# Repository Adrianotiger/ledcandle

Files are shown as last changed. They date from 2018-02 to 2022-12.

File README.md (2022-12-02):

# ledcandle
Led candle with push button and timer for auto power off

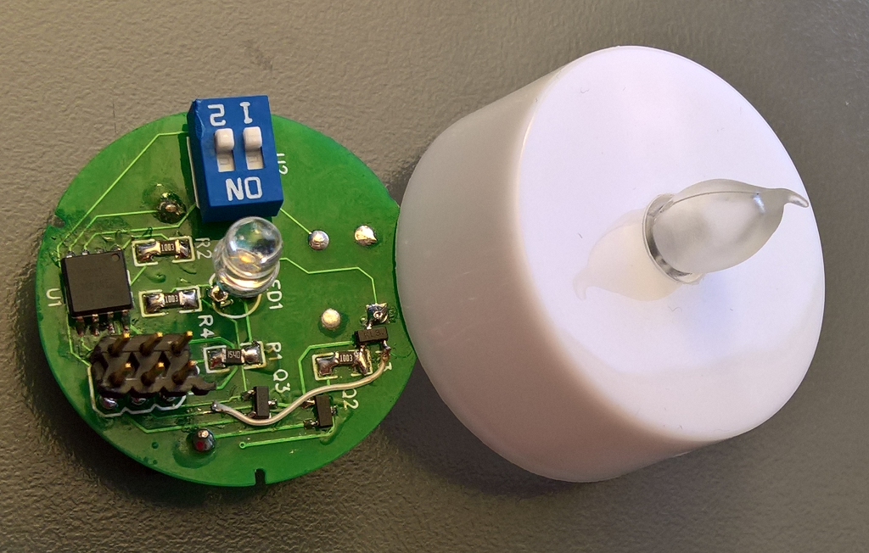
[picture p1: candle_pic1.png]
Candle PCB and case


A project for my [childs room-sky](https://www.youtube.com/watch?v=BvMHdN5_T0Q), it is a candle:
- with auto power off after 10 minutes
- nice and harmonic flicker effects (not aggressive)
- durable, will not be empty after 1 night. Should works for 1 year.
- small, so you can place it in a standard tea-light candle.

It works with an ATTiny45V (Arduino project)

Schematics and PCB are open source and hosted on Easy Eda (see PCB folder): 

https://easyeda.com/tiger54/led_candle-13fe66ec4c4447c1abb9b866b1f16509

3D-print design are hosted on Tinkercad (see 3d-print folder): 

https://www.tinkercad.com/things/0Jzv9iGX0FP
https://www.tinkercad.com/things/gcvcmAciCn8

Copy of the schematics and the Arduino code is hosted on GitHub.

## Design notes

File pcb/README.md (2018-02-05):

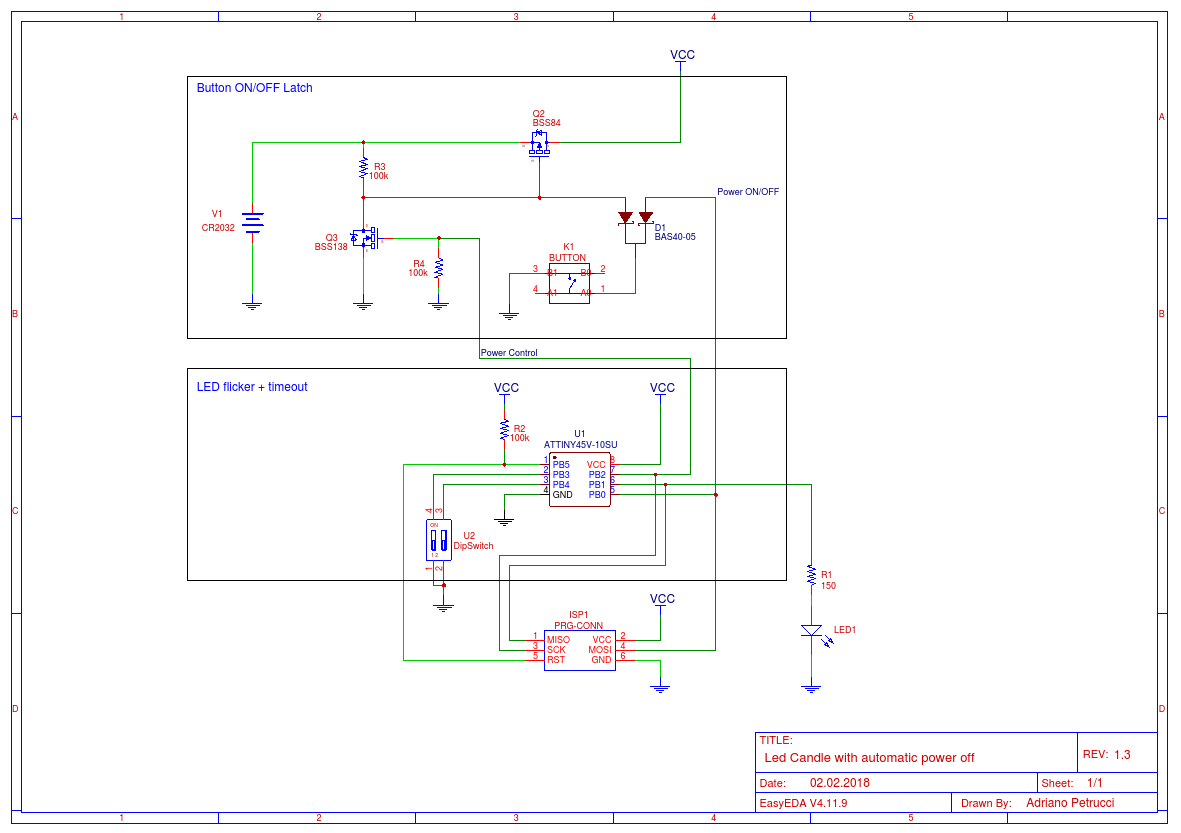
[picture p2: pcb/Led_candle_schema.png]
Led Candle Schema, version 1.3


# Schematics

## How it works
The print is divided in 2 parts. A power latch and the timer control.
Once you press the push bush button, the µC will be powered and will auto power itself until the timeout is over or if the push button is pressed again.
There is a dipswitch that can be used to set some variables inside the code or to program the attiny.

## components / BOM

| Qty | Component | Price ($) | Description |
|-----|---|---|---|
|  1  | V1, Battery holder | 0.06$ | A simple 2032 battery with 230mAh, will power the module for 25-40 hours |
|  1  | Q2, BSS84 | 0.02$ | P-channel MOSFET. Once the switch is pressed, the FET will power on the entire module (VCC = battery voltage) |
|  1  | Q3, BSS138 | 0.02$ | N-channel MOSFET. The µC will activate it (high on gate). Once the µC will set the gate to low, the P-MOSFET will close (VCC = 0V) |
|  1  | K1, Push button | 0.02$ | To power on (and power off) the module. In my project I use a bridge near the LED |
|  1  | LED | 0.01$ | A bright yellow/orange/ambra LED. Something like 8000 mcd at 20mA. Search a LED that works with 1-2V, not 4-5V! |
|  1  | R2,R3,R4 100kΩ | 0.01$ | 2 pullups and 1 pulldown resistors, 10k would also works, but R3 should be as high as possible |
|  1  | R1 150Ω | 0.01$ | LED resistor, choose the resistor for your LED. You should not power the LED with more than 20mA - 5mA in my project |
|  1  | ISP1 Conn. | 0.01$ | A connector (if you want) to program the ATTiny45V, holes are enough small to put the programming connector directly in the PCB |
|  1  | U2 DipSwitch | 0.15$ | Not necessary, you can bridge the pins directly, as this is an expensive component |
|  1  | D1 BAS40-05 | 0.02$ | Dual schottky diode. You need this if you want detect a second press over the µC.* |
|  1  | U1 ATTiny45V | 1.40$ | AT Tiny45 V, is like the AT Tiny45 but you can power it from 1.8V to 5.5V (the normal one only from 2.7 to 5.5V)** |
|  ∞  | 2032 Battery | 0.50$ | A simple 2032 battery, you can get them from 0.10$ up to 1$. Don't know if there is a big difference) |
|  1  | PCB print | 0.40$ | If you buy 5, you have to pay 2$ on easyeda.com |

## Troubles
***Schottky (D1):***

The main problem there is the reverse current. The module will consume even if it should be powered off. *BAS40-05* has only 10nA reverse current, in this way you can detect the switch wihtout loose too much current - you will loose 1% of your battery capacity each year. 
Another way is to remove the connection between µC and switch (cut the track on the PCB between the 2 pads). You will not be able to power off the led anymore but the module will power on also after 10 years.

***ATTiny45V (U1):***

Pratically impossible to find on cheaps shops, this ATTiny is made to works on low voltages. The normal ATTiny works with at least 2.7V but the 3V battery will go down up to 2.0V when discharging. So the only way is to use this V-type ATTiny. The rest is perfect:
4kB program memory, 256 bytes of RAM and even 256 bytes of ROM with a clock that works up to 10MHz (we use only 2kB and 50 bytes of RAM and need a clock of 1MHz, this will reduce the consumption a little bit).

***MOSFETS:***

BSS84 and BSS138, maybe not the best ones but the cheapest on the market. Perfect for this work.

***Battery Holder***

The one used on this project is really big! There are smaller holders, SMD holders for example. If you want a flat module, you have to choose another type.

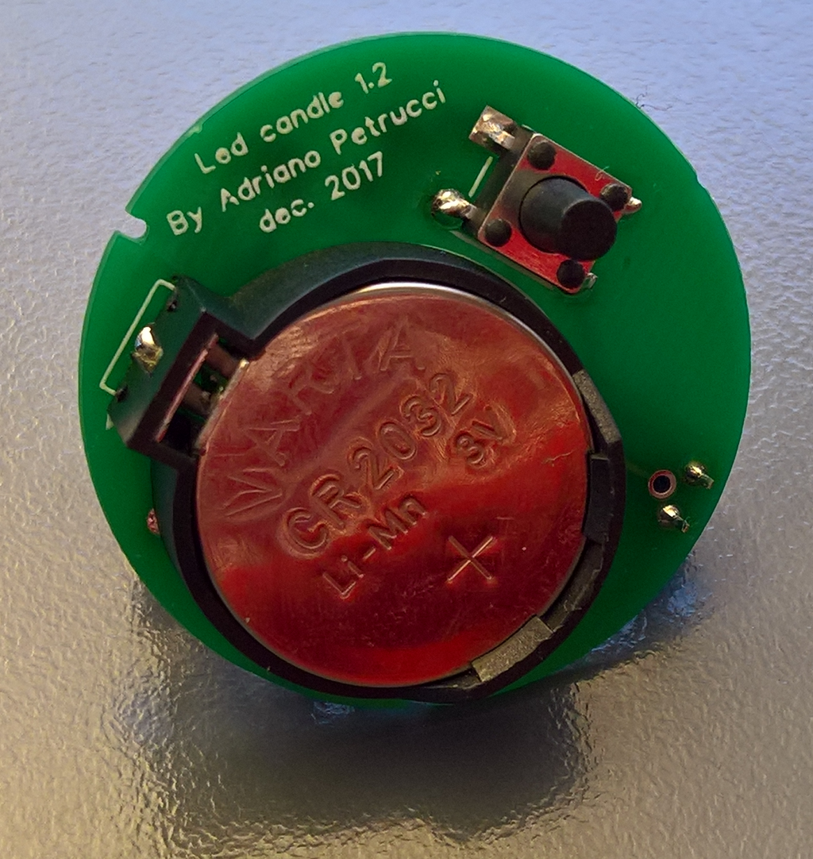
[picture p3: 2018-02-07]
candle_pic2.png

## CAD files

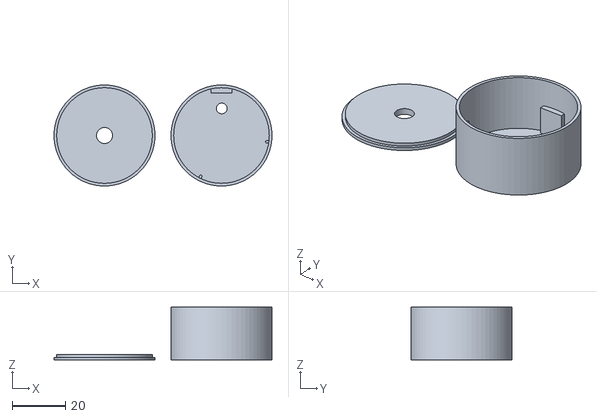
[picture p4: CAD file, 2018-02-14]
3d-print/Led Candle.stl
82.0 x 38.0 x 19.9

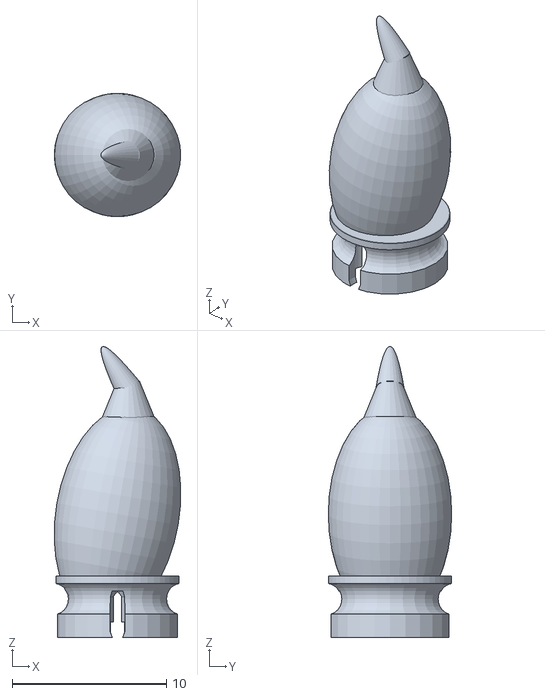
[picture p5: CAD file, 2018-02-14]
3d-print/Led Flame.stl
8.20 x 8.00 x 18.9

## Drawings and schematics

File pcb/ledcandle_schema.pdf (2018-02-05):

### VCC

## Button ON/OFF Latch

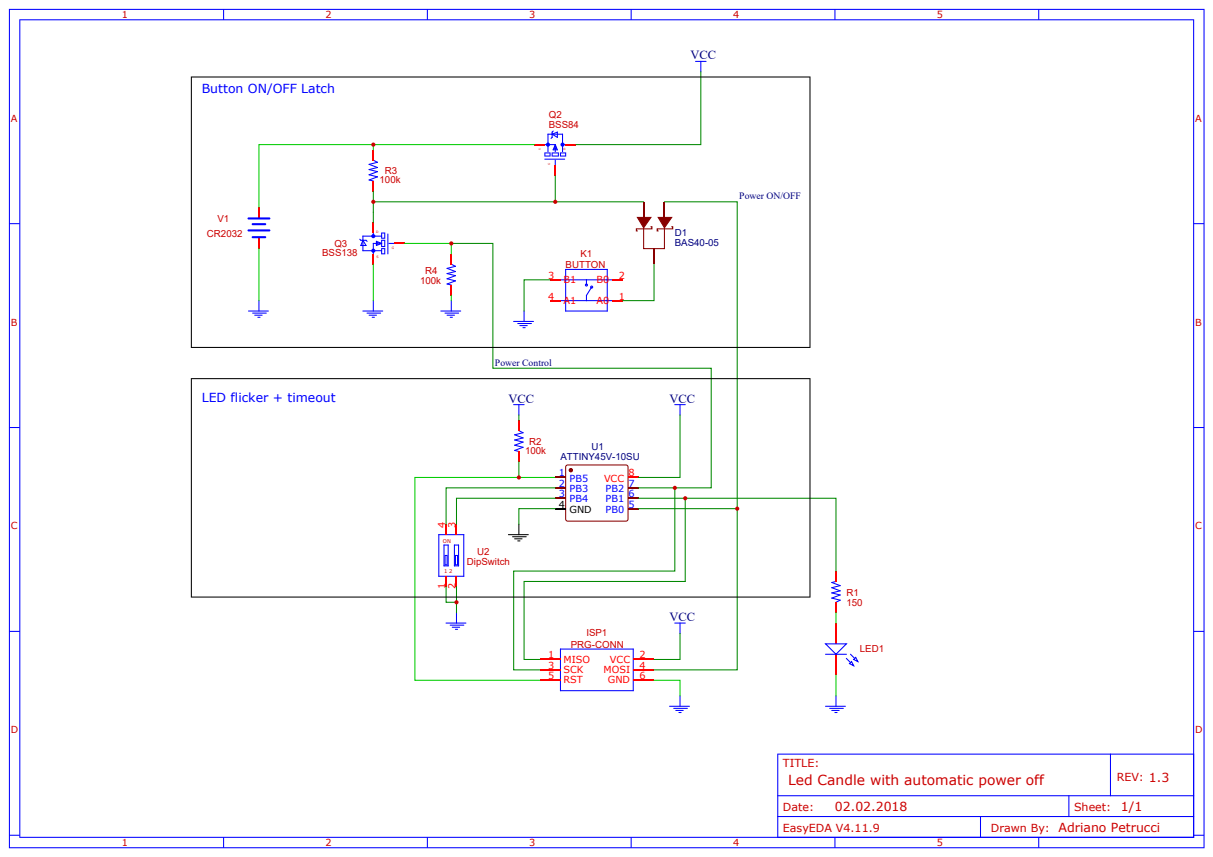
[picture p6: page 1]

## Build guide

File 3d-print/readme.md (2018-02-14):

# 3D Print

On this page you can find a copy of the original design.

All 3D designs are hosted on tinkercad (newest version):

https://www.tinkercad.com/#/?type=all&collection=projects&id=arrGRzcBZGx

To print the case, use a white filament.

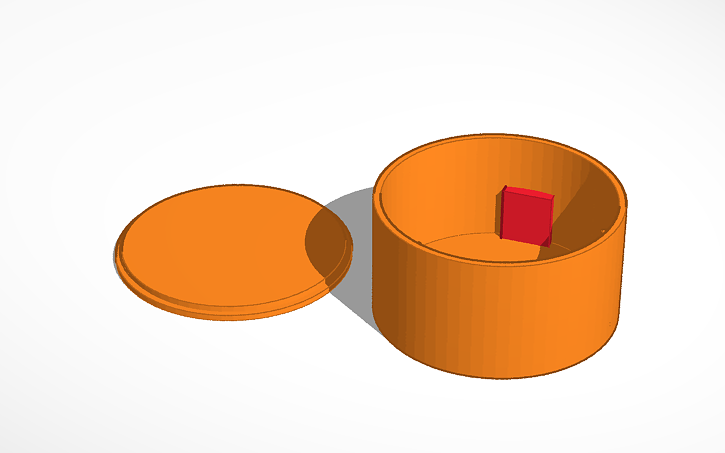
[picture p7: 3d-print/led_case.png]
case


To print the flame, use a transparent filament.

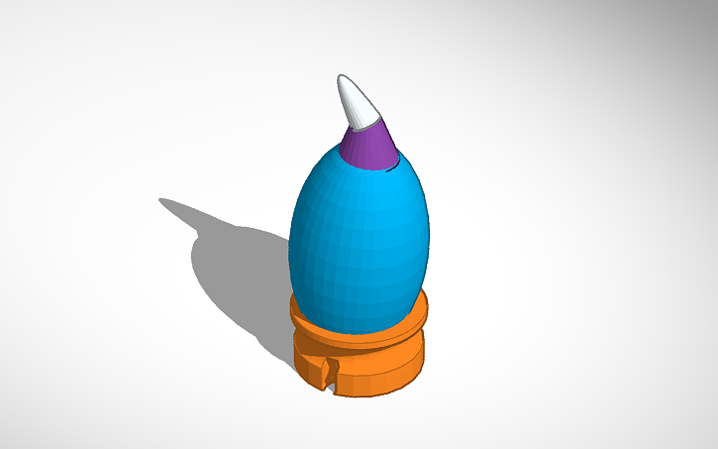
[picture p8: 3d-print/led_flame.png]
flame


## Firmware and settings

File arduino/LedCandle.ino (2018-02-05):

/*
 * Project: LED Candle
 * Author: Adriano Petrucci
 * Date: Feb. 2018
 * Description: Will flicker a LED for 5-10 minutes and then power off.
 *              To save energy, the uC will go to sleep for 4 seconds after each flicker
 * Version: 1.0
 * 
 * References:
 * Flicker code: https://github.com/aShure/arduino_sketches/tree/master/Candle
 */


#include <avr/sleep.h>
#include <avr/power.h>
#include <avr/interrupt.h>
#include <avr/wdt.h>

  // Define PINs
uint8_t pinPower  = 2;    // Used to power the ATTiny
uint8_t pinLed    = 1;    // LED
uint8_t pinInt    = 0;    // Push button interrupt
uint8_t pinInp1   = 3;    // Switch 1
uint8_t pinInp2   = 4;    // Switch 2

  // the start of the flicker (low)
uint8_t flicker_low_min = 190;
uint8_t flicker_low_max = 230;
  // the end value of the flicker (high)
uint8_t flicker_high_min = 220;
uint8_t flicker_high_max = 255;
  // delay between each low-high-low cycle
  // low->high |flicker_hold| high->low
static uint16_t flicker_hold_min = 50; // milliseconds
static uint16_t flicker_hold_max = 90; // milliseconds
  // delay after each low-high-low cycle
  // low->high->low |flicker_pause| low->high...
static uint16_t flicker_pause_min = 100; // milliseconds
static uint16_t flicker_pause_max = 200;  // milliseconds
  // delay low to high and high to low cycle
static uint16_t flicker_speed_min = 500; // microseconds
static uint16_t flicker_speed_max = 1000; // microseconds

uint8_t flicker_random_low_start = 0;
uint8_t flicker_random_low_end = 0;
uint8_t flicker_random_high = 0;
uint16_t flicker_random_speed_start = 0;
uint16_t flicker_random_speed_end = 0;

  // How long the module should be powered on
volatile uint32_t autoPowerOffTime = 1000L * 60 * 10;  // 10 minutes
  // millis() does not work on this example, as we don't have an external timer and we go to sleep every 4-8 seconds
volatile uint32_t onTime = 0L; 
  // used to add time to onTime
volatile uint32_t tempMillis = 0L;
  // push button pressed (power off candle)
volatile bool powerOffCandle = false;

void setup() 
{
  power_adc_disable();            // Don't need an Analog Digital Converter
  power_usi_disable();            // Don't need the Universal Serial Interface
  power_timer1_disable();         // Don't need the Timer1

  pinMode(pinPower, OUTPUT);      // Auto power the module
  digitalWrite(pinPower, HIGH);
  pinMode(pinLed, OUTPUT);        // LED pin (PWM)

  pinMode(pinInt, INPUT_PULLUP);  // Interrupt
  pinMode(pinInp1, INPUT_PULLUP); // Switch 1
  pinMode(pinInp2, INPUT_PULLUP); // Switch 2

  GIMSK = 0b00100000;             // turns on pin change interrupts
  PCMSK = (1 << pinInt);          // turn on interrupts on pins PB0
  sei();                          // enables interrupts

  set_sleep_mode(SLEEP_MODE_PWR_DOWN);   // sleep mode is set here (SLEEP_MODE_IDLE if PWM must still be active) - SLEEP_MODE_PWR_DOWN -> SLEEP_MODE_STANDBY -> SLEEP_MODE_PWR_SAVE

  setup_watchdog(WDTO_4S);        // approximately 4 seconds sleep

  powerOffCandle = false;         // true if candle need to power off
  autoPowerOffTime = 1000L * 20;  // 20 seconds

    // nice power on effect
  for(uint8_t k=0;k<10;k++)
  {
    analogWrite(pinLed, (k%2)==0?k*k*2:k*k);
    delay(50);
  }
}

void loop() 
{
  tempMillis = millis();  // calculate the millis used for the flicker animation
  
    // random time for low
  flicker_random_low_start = random(flicker_low_min, flicker_low_max);
  flicker_random_low_end = random(flicker_low_min, flicker_low_max);
   
    // random time for high
  flicker_random_high = random(flicker_high_min, flicker_high_max);
   
    // random time for speed
  flicker_random_speed_start = random(flicker_speed_min, flicker_speed_max);
  flicker_random_speed_end = random(flicker_speed_min, flicker_speed_max);

     // high -> low
  for (int i = flicker_random_high; i>=flicker_random_low_end; i--) 
  {
    analogWrite(pinLed, i);
    delayMicroseconds(flicker_random_speed_end);
  }
     
    // hold
  delay(random(flicker_hold_min, flicker_hold_max));

    // low -> high
  for (int i = flicker_random_low_start; i<flicker_random_high; i++) 
  {
    analogWrite(pinLed, i);
    delayMicroseconds(flicker_random_speed_start);
  }

  if(random(0,4) == 0 && onTime < autoPowerOffTime)
  {
    onTime += millis() - tempMillis;

    for (int i = flicker_random_high;i<255; i++) 
    {
      analogWrite(pinLed, i);
      delayMicroseconds(flicker_random_speed_start);
    }
    //analogWrite(pinLed, 255);
    do
    {
      system_sleep();
      onTime += 3700;
    } while(random(0,2) == 0);
  }
  else
  {
      // hold
    delay(random(flicker_hold_min, flicker_hold_max));
    onTime += millis() - tempMillis;
  }

    // If timeout or button was pressed
  if(onTime > autoPowerOffTime || powerOffCandle) 
  {
    if(powerOffCandle || flicker_low_min == 0)
    {
      delay(300);
      for(int i=30;i>0;i--)
      {
        analogWrite(pinLed, i);
        delay(30 + (30-i));
      }
      digitalWrite(pinPower, LOW);
      delay(500);
      analogWrite(pinLed, 255);
      delay(5000);
    }
    else if(flicker_low_min > 50) 
    {
      flicker_low_min -= 5;
      flicker_low_max -= 5;
      flicker_high_min -= 4;
      flicker_high_max -= 4;
      if(flicker_speed_min > 100)
      {
        flicker_speed_min -= 50;
        flicker_speed_max -= 50;
      }
    }
    else if(flicker_low_min > 30) 
    {
      flicker_low_min -= 3;
      flicker_low_max = flicker_low_min + flicker_low_max / 5;
      flicker_high_min = flicker_low_min + 20;
      flicker_high_max = flicker_low_min + 30;
      flicker_speed_min = 50;
      flicker_speed_min = 200;
    }
    else
    {
      powerOffCandle = true;
    }
  }
}

  // set system into the sleep state 
  // system wakes up when wtchdog is timed out
void system_sleep() 
{
  sleep_enable();
  sleep_mode();                          // System actually sleeps here
  sleep_disable();                       // System continues execution here when watchdog timed out 
}

  // 0=16ms, 1=32ms,2=64ms,3=128ms,4=250ms,5=500ms
  // 6=1 sec,7=2 sec, 8=4 sec, 9= 8sec
void setup_watchdog(uint8_t ii) 
{ 
  byte bb;
  uint8_t ww;
  if (ii > 9 ) ii=9;
  bb = ii & 7;
  if (ii > 7) bb |= (1<<5);
  bb |= (1<<WDCE);
  ww = bb;
  MCUSR &= ~(1<<WDRF);
  // start timed sequence
  WDTCR |= (1<<WDCE) | (1<<WDE);
  // set new watchdog timeout value
  WDTCR = bb;
  WDTCR |= _BV(WDIE);
}


  // Watchdog Interrupt Service / is executed when watchdog timed out
ISR(WDT_vect) 
{
  // Coming out from sleep
}

  // Interrupt 0 detected
ISR(PCINT0_vect) 
{
  if(onTime > 100)  // Only after 100ms (debouncing)
  {
    if(digitalRead(pinInt) == LOW)
      powerOffCandle = true;
  }
}
